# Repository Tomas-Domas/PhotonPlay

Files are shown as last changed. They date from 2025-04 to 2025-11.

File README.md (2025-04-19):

# PhotonPlay
Galvonometer scanner display for retro games

## Implemented Features
Galvanometer
- DAC and amplified bipolar signal circuit is built and tested.
- Digilent DA2 control signal generation script and workspace file.

FPGA
- Integrated LUT on BRAM.
- Parallel to serial converter that uses a handshake protocol to talk to DAC.
- HDL module for transmitting LUT values to DAC through PMOD interface.

Known Issues / Bugs
- Op-amps are not properly working as rail-to-rail amplifiers, limiting the range of voltages output to the galvanometer driver circuit.
- HDL modules not fully parameterized for re-use.
- LUT generation script not yet able to generate binary files for more compact HDL code.

## Vivado Instructions:
We'll be programming the the Pynq-Z2 board using Vivado, follow Dr Stitt's setup guide for Lab0:
http://www.gstitt.ece.ufl.edu/courses/fall24/eel4720_5721/labs/

I use Vivado 2021.1 and have had no issues but newer versions are probably also fine.

## Adding the Pnyq-Z2 board to Vivado:
Once Vivado is installed, you'll need to add the Pynq-Z2 board to your setup. You can follow the instructions here:
https://community.element14.com/technologies/fpga-group/b/blog/posts/add-pynq-z2-board-to-vivado

Create a board_files folder inside the boards directory if you don't already have one. To check if the process worked create a Vivado project and keep all the defults selected until you reach the Defualt Part screen. Select the boards tab and search Pynq-Z2. The board should appear like so:


## Port Mapping the board:
Port mapping boards are generally done using an .xdc file. Download the Master XDC file using the Tul website:
https://www.tulembedded.com/FPGA/ProductsPYNQ-Z2.html#:~:text=Z2%20Board%20File


Inside the extracted download you'll see a tcl and xdc file. The video below walks you through making an example project with the Pynq-Z2 board and how to use the tcl and xdc file to interface with it:
https://youtu.be/AG15wnyXWaA

Around the 1:36 mark I run the command:
get_property CONFIG.XXXX [get_bd_cells processing_system7_0]

Go into the tcl file and test running this command on random settings like the CONFIG.PCW_DDR_RAM_BASEADDR. This command should return the value given in the tcl file (for instance if running CONFIG.PCW_DDR_RAM_BASEADDR it should return 0x00100000). If this command returns an value that does not align with the tcl file then something went awry. Finally add the xdc file to constraints. The xdc file is currently how pin mapping will be done.

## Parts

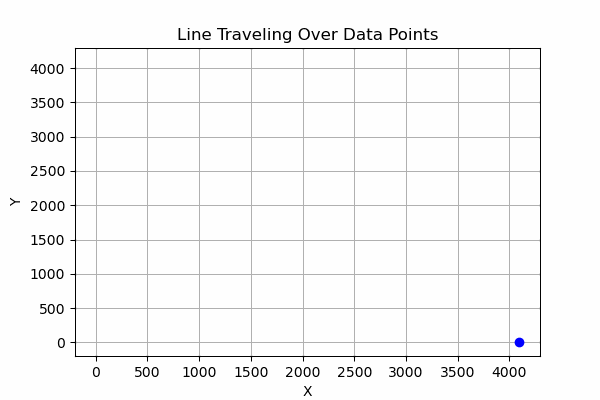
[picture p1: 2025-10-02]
demo materials/tb/drawing.gif

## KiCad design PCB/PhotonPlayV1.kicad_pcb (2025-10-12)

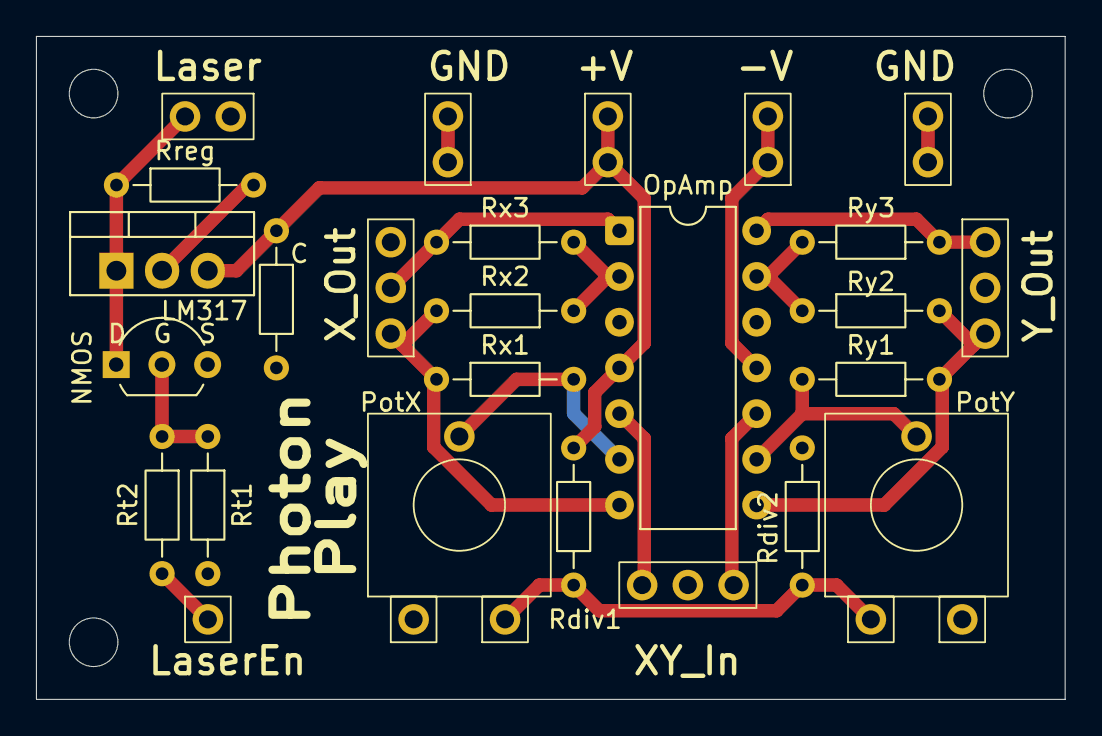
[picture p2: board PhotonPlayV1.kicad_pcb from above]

Board: 2 copper layers, 57.1 x 36.8 mm, 29 parts (0 on the bottom side), 18 nets.

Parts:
${VALUE}: Rreg; R_Axial_DIN0204_L3.6mm_D1.6mm_P7.62mm_Horizontal
${VALUE}#2: OpAmp; DIP-14_W7.62mm
${VALUE}#3: NMOS; TO-92L_Inline_Wide
+15V1: +15V; PhotonPlay_Header01x02
-15V1: -15V; PhotonPlay_Header01x02
C: C_Small; R_Axial_DIN0204_L3.6mm_D1.6mm_P7.62mm_Horizontal
GND1, GND2: GND; PhotonPlay_Header01x02
H1, H2, H3: MountingHole; MountingHole_2.7mm
LM317: LM317_TO-220; TO-220-3_Vertical
Laser1: Laser; PhotonPlay_Header01x02
LaserEn1: LaserEn; PhotonPlay_Header01x01
PotX1: PotX; PhotonPlay_Potentiometer
PotY1: PotY; PhotonPlay_Potentiometer
Rdiv1: 22k; R_Axial_DIN0204_L3.6mm_D1.6mm_P7.62mm_Horizontal
Rdiv2: 10k; R_Axial_DIN0204_L3.6mm_D1.6mm_P7.62mm_Horizontal
Rt1: 100; R_Axial_DIN0204_L3.6mm_D1.6mm_P7.62mm_Horizontal
Rt2: 10k; R_Axial_DIN0204_L3.6mm_D1.6mm_P7.62mm_Horizontal
Rx1: 4.7k; R_Axial_DIN0204_L3.6mm_D1.6mm_P7.62mm_Horizontal
Rx2, Rx3: 10k; R_Axial_DIN0204_L3.6mm_D1.6mm_P7.62mm_Horizontal
Ry1: 4.7k; R_Axial_DIN0204_L3.6mm_D1.6mm_P7.62mm_Horizontal
Ry2, Ry3: 10k; R_Axial_DIN0204_L3.6mm_D1.6mm_P7.62mm_Horizontal
XY_Input1: XY_In; PhotonPlay_Header01x03
X_Output1: X_Out; PhotonPlay_Header01x03
Y_Output1: Y_Out; PhotonPlay_Header01x03

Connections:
+15V: ${VALUE}#2.4 (V+), +15V1.1, +15V1.2, C.1, LM317.3 (VI), Rdiv1.2
/+5V: PotX1.3, PotY1.1, Rdiv1.1, Rdiv2.2
/-15V: ${VALUE}#2.11 (V-), -15V1.1, -15V1.2
/Gate: ${VALUE}#3.2 (G), Rt1.1, Rt2.1
/Vreg: ${VALUE}.1, ${VALUE}#3.1 (D), LM317.1 (ADJ), Laser1.2
/X+: ${VALUE}#2.7, Rx1.1, Rx2.2, X_Output1.1
/X-: ${VALUE}#2.1, Rx3.1, X_Output1.2
/X_In: ${VALUE}#2.5 (+), XY_Input1.3
/Y+: ${VALUE}#2.8, Ry1.1, Ry2.2, Y_Output1.3
/Y-: ${VALUE}#2.14, Ry3.1, Y_Output1.1
/Y_In: ${VALUE}#2.10 (+), XY_Input1.1
GND: ${VALUE}#2.3 (+), ${VALUE}#2.12 (+), ${VALUE}#3.3 (S), C.2, GND1.1, GND1.2, GND2.1, GND2.2, Laser1.1, Rdiv2.1, Rt2.2, XY_Input1.2, X_Output1.3, Y_Output1.2
unnamed: ${VALUE}.2, LM317.2 (VO)
unnamed: LaserEn1.1, Rt1.2
unnamed: ${VALUE}#2.2 (-), Rx2.1, Rx3.2
unnamed: ${VALUE}#2.6 (-), PotX1.2, Rx1.2
unnamed: ${VALUE}#2.9 (-), PotY1.2, Ry1.2
unnamed: ${VALUE}#2.13 (-), Ry2.1, Ry3.2

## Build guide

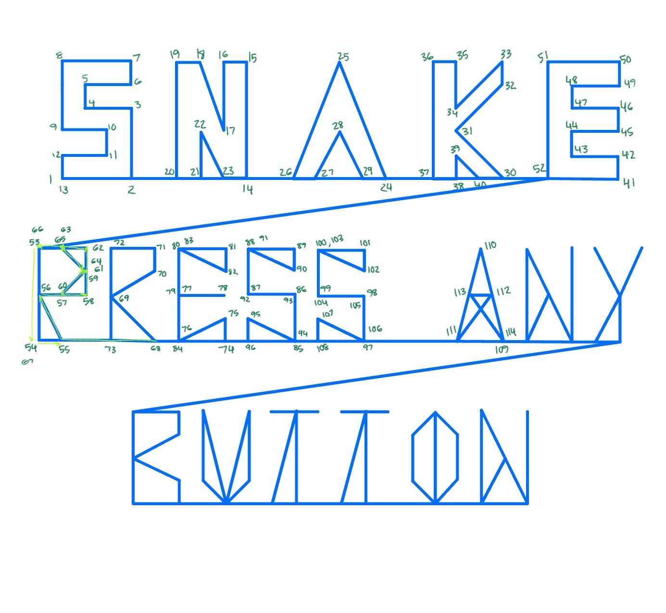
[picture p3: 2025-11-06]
Asset_Maker/hi.jpg

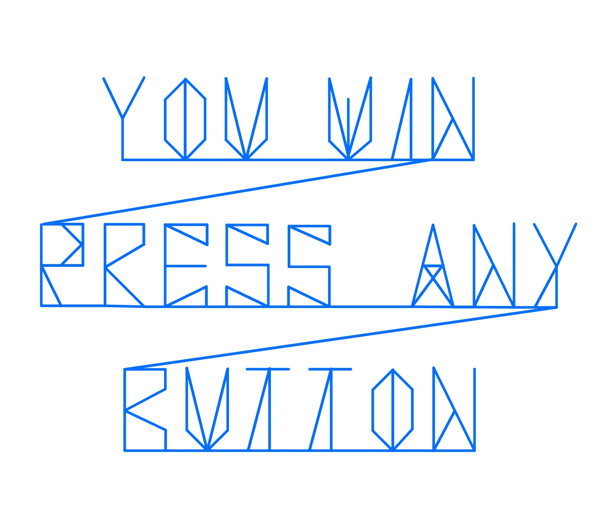
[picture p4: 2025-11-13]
Asset_Maker/hi2.jpeg

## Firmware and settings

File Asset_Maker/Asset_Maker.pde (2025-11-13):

int DRAW_GRID_RESOLUTION = 150;
int ALIGNMENT_SPACING = 8;

float DRAW_GRID_SIZE;
float POINT_SIZE;
float LINE_SIZE;

int SCALING_GRID_RESOLUTION = 32;
float SCALING_GRID_SIZE;
float SCALING_FACTOR;

ArrayList<Point> points = new ArrayList<Point>();
Point currentPoint = new Point(0, 0);

PImage img;

final int DRAW_MODE = 0;
final int SCALE_MODE = 1;

int state = DRAW_MODE;

void setup() {
    size(760, 760);
    
    fill(255, 0, 0);
    rectMode(CENTER);

    points.add(currentPoint);
    
    DRAW_GRID_SIZE  = min(((float)width / DRAW_GRID_RESOLUTION), ((float)height / DRAW_GRID_RESOLUTION));
    SCALING_GRID_SIZE  = min(((float)width / SCALING_GRID_RESOLUTION), ((float)height / SCALING_GRID_RESOLUTION));
    POINT_SIZE = DRAW_GRID_SIZE * 0.8;
    LINE_SIZE  = DRAW_GRID_SIZE * 0.4;
    
    img = loadImage("hi2.jpeg");
    if (img.width > img.height) {
        img.resize(width, 0);
    } else {
        img.resize(0, height);
    }
}


void draw() {
    background(0);

    if (state == DRAW_MODE) {
        drawMode();
    } else if (state == SCALE_MODE) {
        scaleMode();
    }
}


void drawMode() {
    tint(51);
    image(img, 0, 0);

    // Update currentPoint to mouse position
    currentPoint.x = canvasToGrid(mouseX);
    currentPoint.y = canvasToGrid(mouseY);
    
    // Draw grid lines
    stroke(150);
    for (int i = 0; i < DRAW_GRID_RESOLUTION; i++) {

        if((i - DRAW_GRID_RESOLUTION/2) % ALIGNMENT_SPACING == 0 || (i - DRAW_GRID_RESOLUTION/2 - 1) % ALIGNMENT_SPACING == 0) {
            strokeWeight(1);
        } else {
            strokeWeight(0.2);
        }

        int offset = (int)((i) * DRAW_GRID_SIZE);
        line(offset, 0,   offset, height);
        line(0, offset,   width, offset);
    }

    // Draw circles and lines connecting them
    for (int i = 0; i < points.size(); i++) {
        Point current = points.get(i);
        noStroke();
        circle(
            gridToDrawCanvas(current.x),
            gridToDrawCanvas(current.y),
            POINT_SIZE
        );
        
        stroke(255, 0, 0);
        strokeWeight(DRAW_GRID_SIZE * 0.3);

        if(i == 0)
            continue;

        Point previous = points.get(i-1);
        if (previous.laser_en) {
            line(
                gridToDrawCanvas(current.x), 
                gridToDrawCanvas(current.y), 
                gridToDrawCanvas(previous.x), 
                gridToDrawCanvas(previous.y)
            );
        }
    }
}


void scaleMode() {
    // Draw grid lines
    stroke(150);
    strokeWeight(0.2);
    for (int i = 0; i < SCALING_GRID_RESOLUTION; i++) {
        int offset = (int)((i) * SCALING_GRID_SIZE);
        line(offset, 0,   offset, height);
        line(0, offset,   width, offset);
    }

    // Draw shape
    stroke(255, 0, 0);
    strokeWeight(floor(SCALING_FACTOR * 0.2 + 1));
    for (int i = 1; i < points.size()-1; i++) {
        Point current = points.get(i);
        Point previous = points.get(i-1);

        if (previous.laser_en) {
            line(
                gridToScaleCanvas(current.x)  + mouseX,
                gridToScaleCanvas(current.y)  + mouseY,
                gridToScaleCanvas(previous.x) + mouseX,
                gridToScaleCanvas(previous.y) + mouseY
            );
        }
    }
}


void mousePressed() {
    if (mouseButton == LEFT) {
        leftClick();
    } else if (mouseButton == RIGHT) {
        rightClick();
    }
}


void leftClick() {
    currentPoint = new Point(0, 0);
    points.add(currentPoint);
}


void rightClick() {
    int col = canvasToGrid(mouseX);
    int row = canvasToGrid(mouseY);

    for (int i = points.size()-2; i >= 0; i--) {
        if (points.get(i).x == col && points.get(i).y == row) {
            points.remove(i);
            return;
        }
    }
}


void keyPressed() {
    if (state == DRAW_MODE) {
        if (key == CODED) {
            if (keyCode == UP) {
                for (int i = 0; i < points.size(); i++)
                    points.get(i).y--;
                return;
            }
            if (keyCode == DOWN) {
                for (int i = 0; i < points.size(); i++)
                    points.get(i).y++;
                return;
            }
            if (keyCode == LEFT) {
                for (int i = 0; i < points.size(); i++)
                    points.get(i).x--;
                return;
            }
            if (keyCode == RIGHT) {
                for (int i = 0; i < points.size(); i++)
                    points.get(i).x++;
                return;
            }

            println(keyCode);

        } else {
            if (key == ' ') {
                if (points.size() > 1)
                    points.get(points.size()-2).laser_en ^= true;  // toggle laser_en
                return;
            }
            if (key == ENTER) {
                SCALING_FACTOR = DRAW_GRID_RESOLUTION / 4096.0 * 50.0;
                state = SCALE_MODE;
                println("Switching to Scaling Mode");
                return;
            }

            println(key);

        }
    }

    else if (state == SCALE_MODE) {
        if (key == CODED) {
            if (keyCode == UP) {
                SCALING_FACTOR *= 1.1;
                return;
            }
            if (keyCode == DOWN) {
                SCALING_FACTOR /= 1.1;
                return;
            }

            println(keyCode);

        } else {
            if (key == ENTER) {
                println("Writing LUT to File");
                writeToFile();
                state = DRAW_MODE;
                return;
            }

            println(key);

        }
    }
    
}


int canvasToGrid(int coord) {
    return floor(coord / DRAW_GRID_SIZE);
}


float gridToDrawCanvas(int coord) {
    return (coord + 0.5) * DRAW_GRID_SIZE;
}


float gridToScaleCanvas(int coord) {
    return ((coord - DRAW_GRID_RESOLUTION*0.5) * SCALING_FACTOR);
}


void writeToFile() {
    PrintWriter fileX = createWriter("lut_x.txt");
    PrintWriter fileY = createWriter("lut_y.txt");

    for (int i = 0; i < points.size()-2; i++) {
        int x = round((gridToScaleCanvas(points.get(i).x)  + mouseX) * 4096.0 / width);
        int y = round((gridToScaleCanvas(points.get(i).y)  + mouseY) * 4096.0 / width);

        fileX.printf("rom[%d] = 12'd%d;\n", i, x);
        fileY.printf("rom[%d] = 12'd%d;\n", i, y);
    }

    fileX.flush();
    fileY.flush();

    fileX.close();
    fileY.close();
}

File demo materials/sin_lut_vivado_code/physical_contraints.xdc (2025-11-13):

## This file is a general .xdc for the PYNQ-Z2 board 
## To use it in a project:
## - uncomment the lines corresponding to used pins
## - rename the used ports (in each line, after get_ports) according to the top level signal names in the project

## Clock signal 125 MHz

set_property -dict { PACKAGE_PIN H16   IOSTANDARD LVCMOS33 } [get_ports { sys_clock }]; #IO_L13P_T2_MRCC_35 Sch=sysclk
create_clock -add -name sys_clk_pin -period 8.00 -waveform {0 4} [get_ports { sys_clock }];

##Switches

set_property -dict { PACKAGE_PIN M20   IOSTANDARD LVCMOS33 } [get_ports { sw0 }]; #IO_L7N_T1_AD2N_35 Sch=sw[0]
# set_property -dict { PACKAGE_PIN M19   IOSTANDARD LVCMOS33 } [get_ports { sw1 }]; #IO_L7P_T1_AD2P_35 Sch=sw[1]

##RGB LEDs

#set_property -dict { PACKAGE_PIN L15   IOSTANDARD LVCMOS33 } [get_ports { led4_b }]; #IO_L22N_T3_AD7N_35 Sch=led4_b
#set_property -dict { PACKAGE_PIN G17   IOSTANDARD LVCMOS33 } [get_ports { led4_g }]; #IO_L16P_T2_35 Sch=led4_g
#set_property -dict { PACKAGE_PIN N15   IOSTANDARD LVCMOS33 } [get_ports { led4_r }]; #IO_L21P_T3_DQS_AD14P_35 Sch=led4_r
#set_property -dict { PACKAGE_PIN G14   IOSTANDARD LVCMOS33 } [get_ports { led5_b }]; #IO_0_35 Sch=led5_b
#set_property -dict { PACKAGE_PIN L14   IOSTANDARD LVCMOS33 } [get_ports { led5_g }]; #IO_L22P_T3_AD7P_35 Sch=led5_g
#set_property -dict { PACKAGE_PIN M15   IOSTANDARD LVCMOS33 } [get_ports { led5_r }]; #IO_L23N_T3_35 Sch=led5_r

##LEDs

set_property -dict { PACKAGE_PIN R14   IOSTANDARD LVCMOS33 } [get_ports { led0 }]; #IO_L6N_T0_VREF_34 Sch=led[0]
# set_property -dict { PACKAGE_PIN P14   IOSTANDARD LVCMOS33 } [get_ports { led1 }]; #IO_L6P_T0_34 Sch=led[1]
#set_property -dict { PACKAGE_PIN N16   IOSTANDARD LVCMOS33 } [get_ports { led[2] }]; #IO_L21N_T3_DQS_AD14N_35 Sch=led[2]
#set_property -dict { PACKAGE_PIN M14   IOSTANDARD LVCMOS33 } [get_ports { led[3] }]; #IO_L23P_T3_35 Sch=led[3]

##Buttons

#set_property -dict { PACKAGE_PIN D19   IOSTANDARD LVCMOS33 } [get_ports { btn[0] }]; #IO_L4P_T0_35 Sch=btn[0]
#set_property -dict { PACKAGE_PIN D20   IOSTANDARD LVCMOS33 } [get_ports { btn[1] }]; #IO_L4N_T0_35 Sch=btn[1]
#set_property -dict { PACKAGE_PIN L20   IOSTANDARD LVCMOS33 } [get_ports { btn[2] }]; #IO_L9N_T1_DQS_AD3N_35 Sch=btn[2]
#set_property -dict { PACKAGE_PIN L19   IOSTANDARD LVCMOS33 } [get_ports { btn[3] }]; #IO_L9P_T1_DQS_AD3P_35 Sch=btn[3]

##PmodA

#set_property -dict { PACKAGE_PIN Y18   IOSTANDARD LVCMOS33 } [get_ports { ja[0] }]; #IO_L17P_T2_34 Sch=ja_p[1]
#set_property -dict { PACKAGE_PIN Y19   IOSTANDARD LVCMOS33 } [get_ports { ja[1] }]; #IO_L17N_T2_34 Sch=ja_n[1]
#set_property -dict { PACKAGE_PIN Y16   IOSTANDARD LVCMOS33 } [get_ports { ja[2] }]; #IO_L7P_T1_34 Sch=ja_p[2]
#set_property -dict { PACKAGE_PIN Y17   IOSTANDARD LVCMOS33 } [get_ports { laser_en }]; #IO_L7N_T1_34 Sch=ja_n[2]

# bottom half of pins
set_property -dict { PACKAGE_PIN U18   IOSTANDARD LVCMOS33 } [get_ports { chip_sel }]; #IO_L12P_T1_MRCC_34 Sch=ja_p[3]
set_property -dict { PACKAGE_PIN U19   IOSTANDARD LVCMOS33 } [get_ports { data_out1 }]; #IO_L12N_T1_MRCC_34 Sch=ja_n[3]
set_property -dict { PACKAGE_PIN W18   IOSTANDARD LVCMOS33 } [get_ports { data_out2 }]; #IO_L22P_T3_34 Sch=ja_p[4]
set_property -dict { PACKAGE_PIN W19   IOSTANDARD LVCMOS33 } [get_ports { dac_clk }]; #IO_L22N_T3_34 Sch=ja_n[4]

##PmodB

#set_property -dict { PACKAGE_PIN W14   IOSTANDARD LVCMOS33 } [get_ports { jb[0] }]; #IO_L8P_T1_34 Sch=jb_p[1]
#set_property -dict { PACKAGE_PIN Y14   IOSTANDARD LVCMOS33 } [get_ports { jb[1] }]; #IO_L8N_T1_34 Sch=jb_n[1]
#set_property -dict { PACKAGE_PIN T11   IOSTANDARD LVCMOS33 } [get_ports { jb[2] }]; #IO_L1P_T0_34 Sch=jb_p[2]
#set_property -dict { PACKAGE_PIN T10   IOSTANDARD LVCMOS33 } [get_ports { jb[3] }]; #IO_L1N_T0_34 Sch=jb_n[2]

# bottom half of pins (Currently Controller)
set_property -dict { PACKAGE_PIN V16   IOSTANDARD LVCMOS33 } [get_ports { btn[0] }]; #IO_L18P_T2_34 Sch=jb_p[3]
set_property -dict { PACKAGE_PIN W13   IOSTANDARD LVCMOS33 } [get_ports { btn[1] }]; #IO_L18N_T2_34 Sch=jb_n[3]
set_property -dict { PACKAGE_PIN V12   IOSTANDARD LVCMOS33 } [get_ports { btn[2] }]; #IO_L4P_T0_34 Sch=jb_p[4]
set_property -dict { PACKAGE_PIN W16   IOSTANDARD LVCMOS33 } [get_ports { btn[3] }]; #IO_L4N_T0_34 Sch=jb_n[4]

##Audio 

#set_property -dict { PACKAGE_PIN M17   IOSTANDARD LVCMOS33 } [get_ports { adr0 }]; #IO_L8P_T1_AD10P_35 Sch=adr0
#set_property -dict { PACKAGE_PIN M18   IOSTANDARD LVCMOS33 } [get_ports { adr1 }]; #IO_L8N_T1_AD10N_35 Sch=adr1
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

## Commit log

2025-04-13 Add presentation demo materials
    [diamond corrected.csv, diamond distorted.csv, sin cos.csv]
2025-04-17 Add function for generating verilog lut
    [diamond corrected.csv, diamond distorted.csv, sin cos.csv]
2025-09-18 Added bound checks and fixed button handling. ~Mylee
    [lut_driver.sv]
2025-09-22 Merged Laser enable into drivers
2025-09-23 Added a clock divider and more points to the triangle, laser_en should now be output from the board. ~Mylee
2025-09-25 Added collision detection between triangle and apple. Apple moves to random spot upon collision. Made things more parameterized, and slight code cleanup. ~Mylee
    [lut_driver.sv]
2025-10-02 Broken, moves too fast and negative directions don't work. ~Mylee
    Resets to middle of screen upon hitting borders, and combined speed and speed_reg blocks into one
    [lut_driver.sv]
2025-10-09 Add KiCad PCB design files
    [PhotonPlayV1.kicad_pcb, PhotonPlayV1.kicad_sch]
2025-10-09 Update PCB layout with solved clearance issues
    [PhotonPlayV1.kicad_pcb]
2025-10-10 Added self-collision to snake
    Changed the velocity to match the snake body size, so it doesn't constantly collide with itself.
    [lut_driver.sv]
2025-10-12 Make final edits and add generated drill and gerber files
    [PhotonPlayV1-B_Cu.gbr, PhotonPlayV1-B_Mask.gbr, PhotonPlayV1-B_Paste.gbr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]
2025-10-23 updated simple tb with btn and laser_en
2025-11-04 Add export function and laser_en toggle to AssetMaker
2025-11-04 added external button support
2025-11-04 fixed last element bug; merged changes
    [lut_driver.sv]
2025-11-06 added start state, and ability to leave win state when button pressed
2025-11-13 New lut for the win condition
    Test by making max num segments = 3, and draw update speedown = 1750. Reset these values to their original value when done, might need to udjust draw update speedown.
    [Asset_Maker.pde, lut_driver.sv]
2025-11-13 FIXED BUTTONS HOLY
2025-11-18 added delay for laser_en
2025-11-20 fixed laser enable
2025-11-20 fixed delay and fixed win screen
    [lut_driver.sv]
